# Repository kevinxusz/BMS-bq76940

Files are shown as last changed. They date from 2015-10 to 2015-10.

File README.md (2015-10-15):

battery managment system based on the BQ76940 from Texus Instruments

This project supports akkupacks from 9 to 15 serial Li-Ion based cells (max. Voltage ~63 Volt). It can balance each cell and turns the charge and discharge MOSFETs to control the system over i2c.

Measuring:

- up to 15 cell voltages
- akkupack voltage
- tempreature (internal + external)
- akkupack current

Protection:

- overcurrent in discharge
- overcurrent in discharge
- overvoltage
- undervoltage

My System

For the dokumentation see /Dokumentation/DA_MB_15.pdf where you can find my hole work (german). The important BMS part is shown in capter 5.

The realized system has the following specifications:

- µC: ATmega168PA
- programming was done in C with Linux in nano and the AVR-Tools (avr-gcc, avr-objcopy, make)
- to programm the µC i use avrdude over USB
- the current system is based on 15 cells and max. 60 Volts
- balancing and loading the akkupack
- balancingcurrent up to ~105 mA
- 3x temp. sensors
- switches current up to ~70 Ampere

All testing and programming was done with the developed EvalBoard. For schematica and layouts see /kicad (http://kicad-pcb.org/).
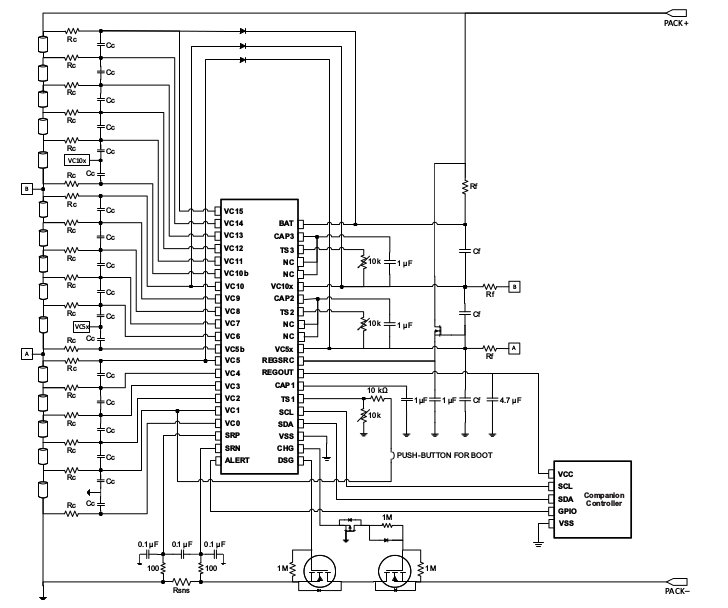
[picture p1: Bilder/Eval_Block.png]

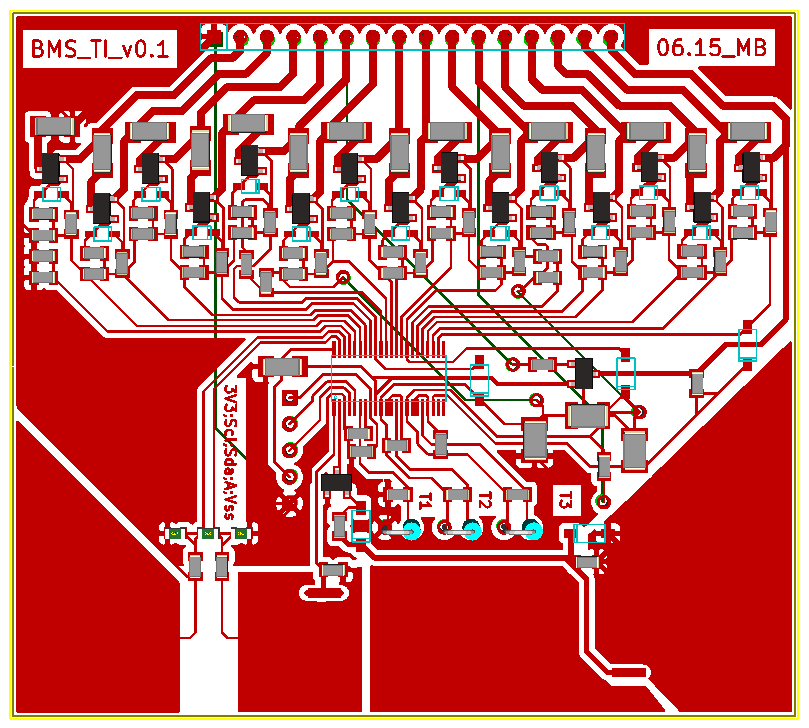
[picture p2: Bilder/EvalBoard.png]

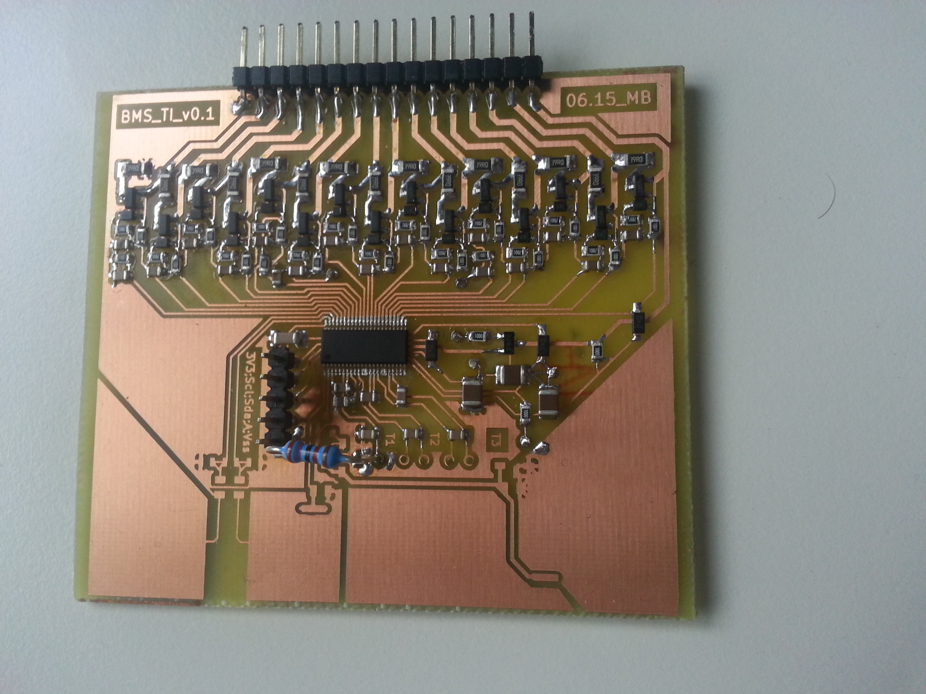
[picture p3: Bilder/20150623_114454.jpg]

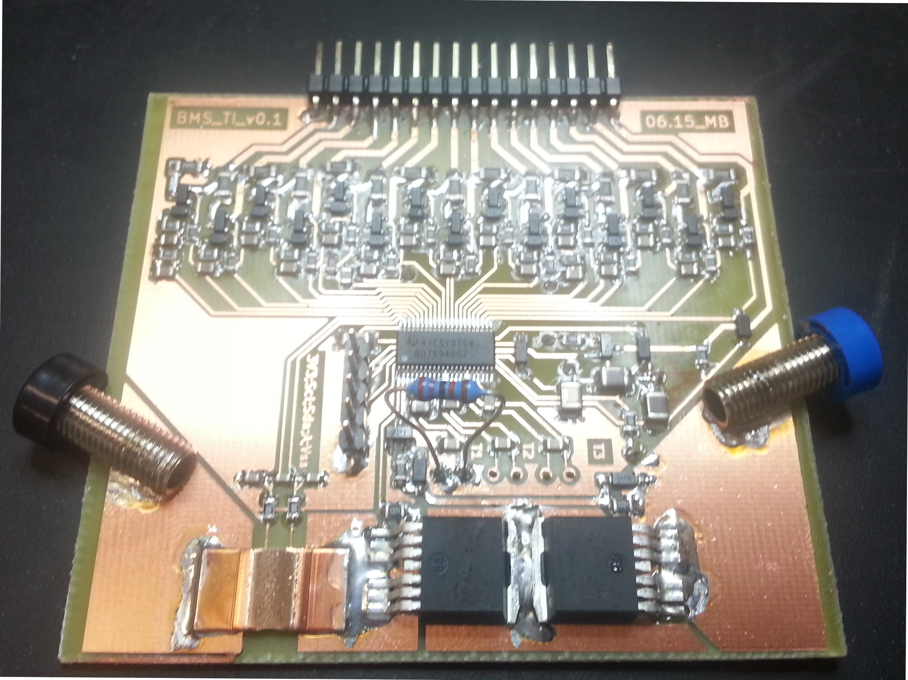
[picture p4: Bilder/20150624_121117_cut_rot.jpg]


For testing the given example run the Makefile (in /Quellcode/Anwendungsbeispiel):
(boot the BQ76940 with 3.3V on TS1) (bootet if 3.3V on REGOUT/3V3_init)

    make clean
    make all
    sudo make load

ToDO:

testing heating distribution under use
testing current measuring funktion

License Information

This code is public domain to support electromobility and is a collaboration between Nathan Seidle (https://github.com/nseidle/BMS) and me.

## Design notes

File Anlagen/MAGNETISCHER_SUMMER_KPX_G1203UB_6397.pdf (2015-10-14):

## Technical datasheet: KPX-G1203UB-K6397

Specifications:

Operating Temperature | -20ºC to +70ºC
Storage Temperature | -30ºC to +80ºC
Rated Voltage | 3 VDC
Operating Voltage | 2VDC to 5VDC
Max. Rated Current | 30mA at 3 VDC
Resonant Frequency | 2.3kHz±0.5kHz
Min SPL | 85dB/ 3VDC/ 10cm
Weight | 2g
Case Material/Color | PBT/Black
Tone Nature | Continuous

Dimensions:

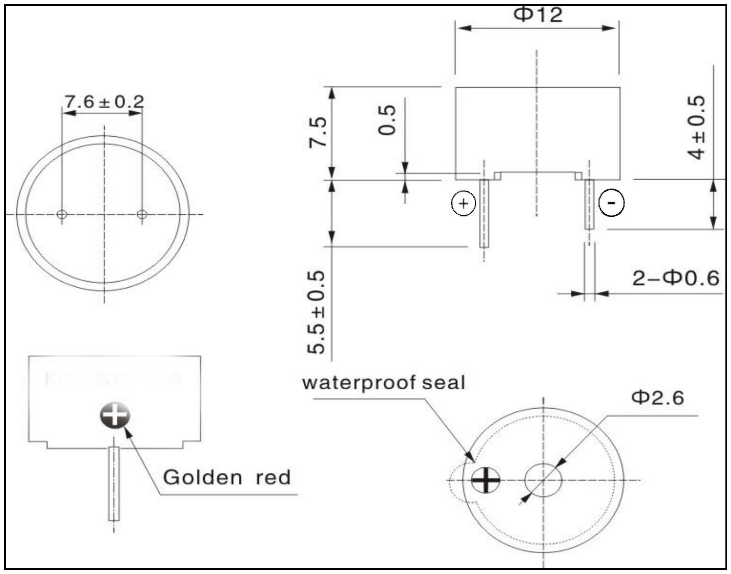
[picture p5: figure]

Frequency Response:

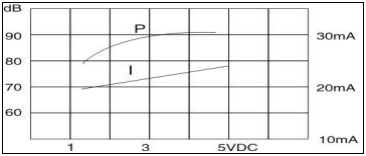
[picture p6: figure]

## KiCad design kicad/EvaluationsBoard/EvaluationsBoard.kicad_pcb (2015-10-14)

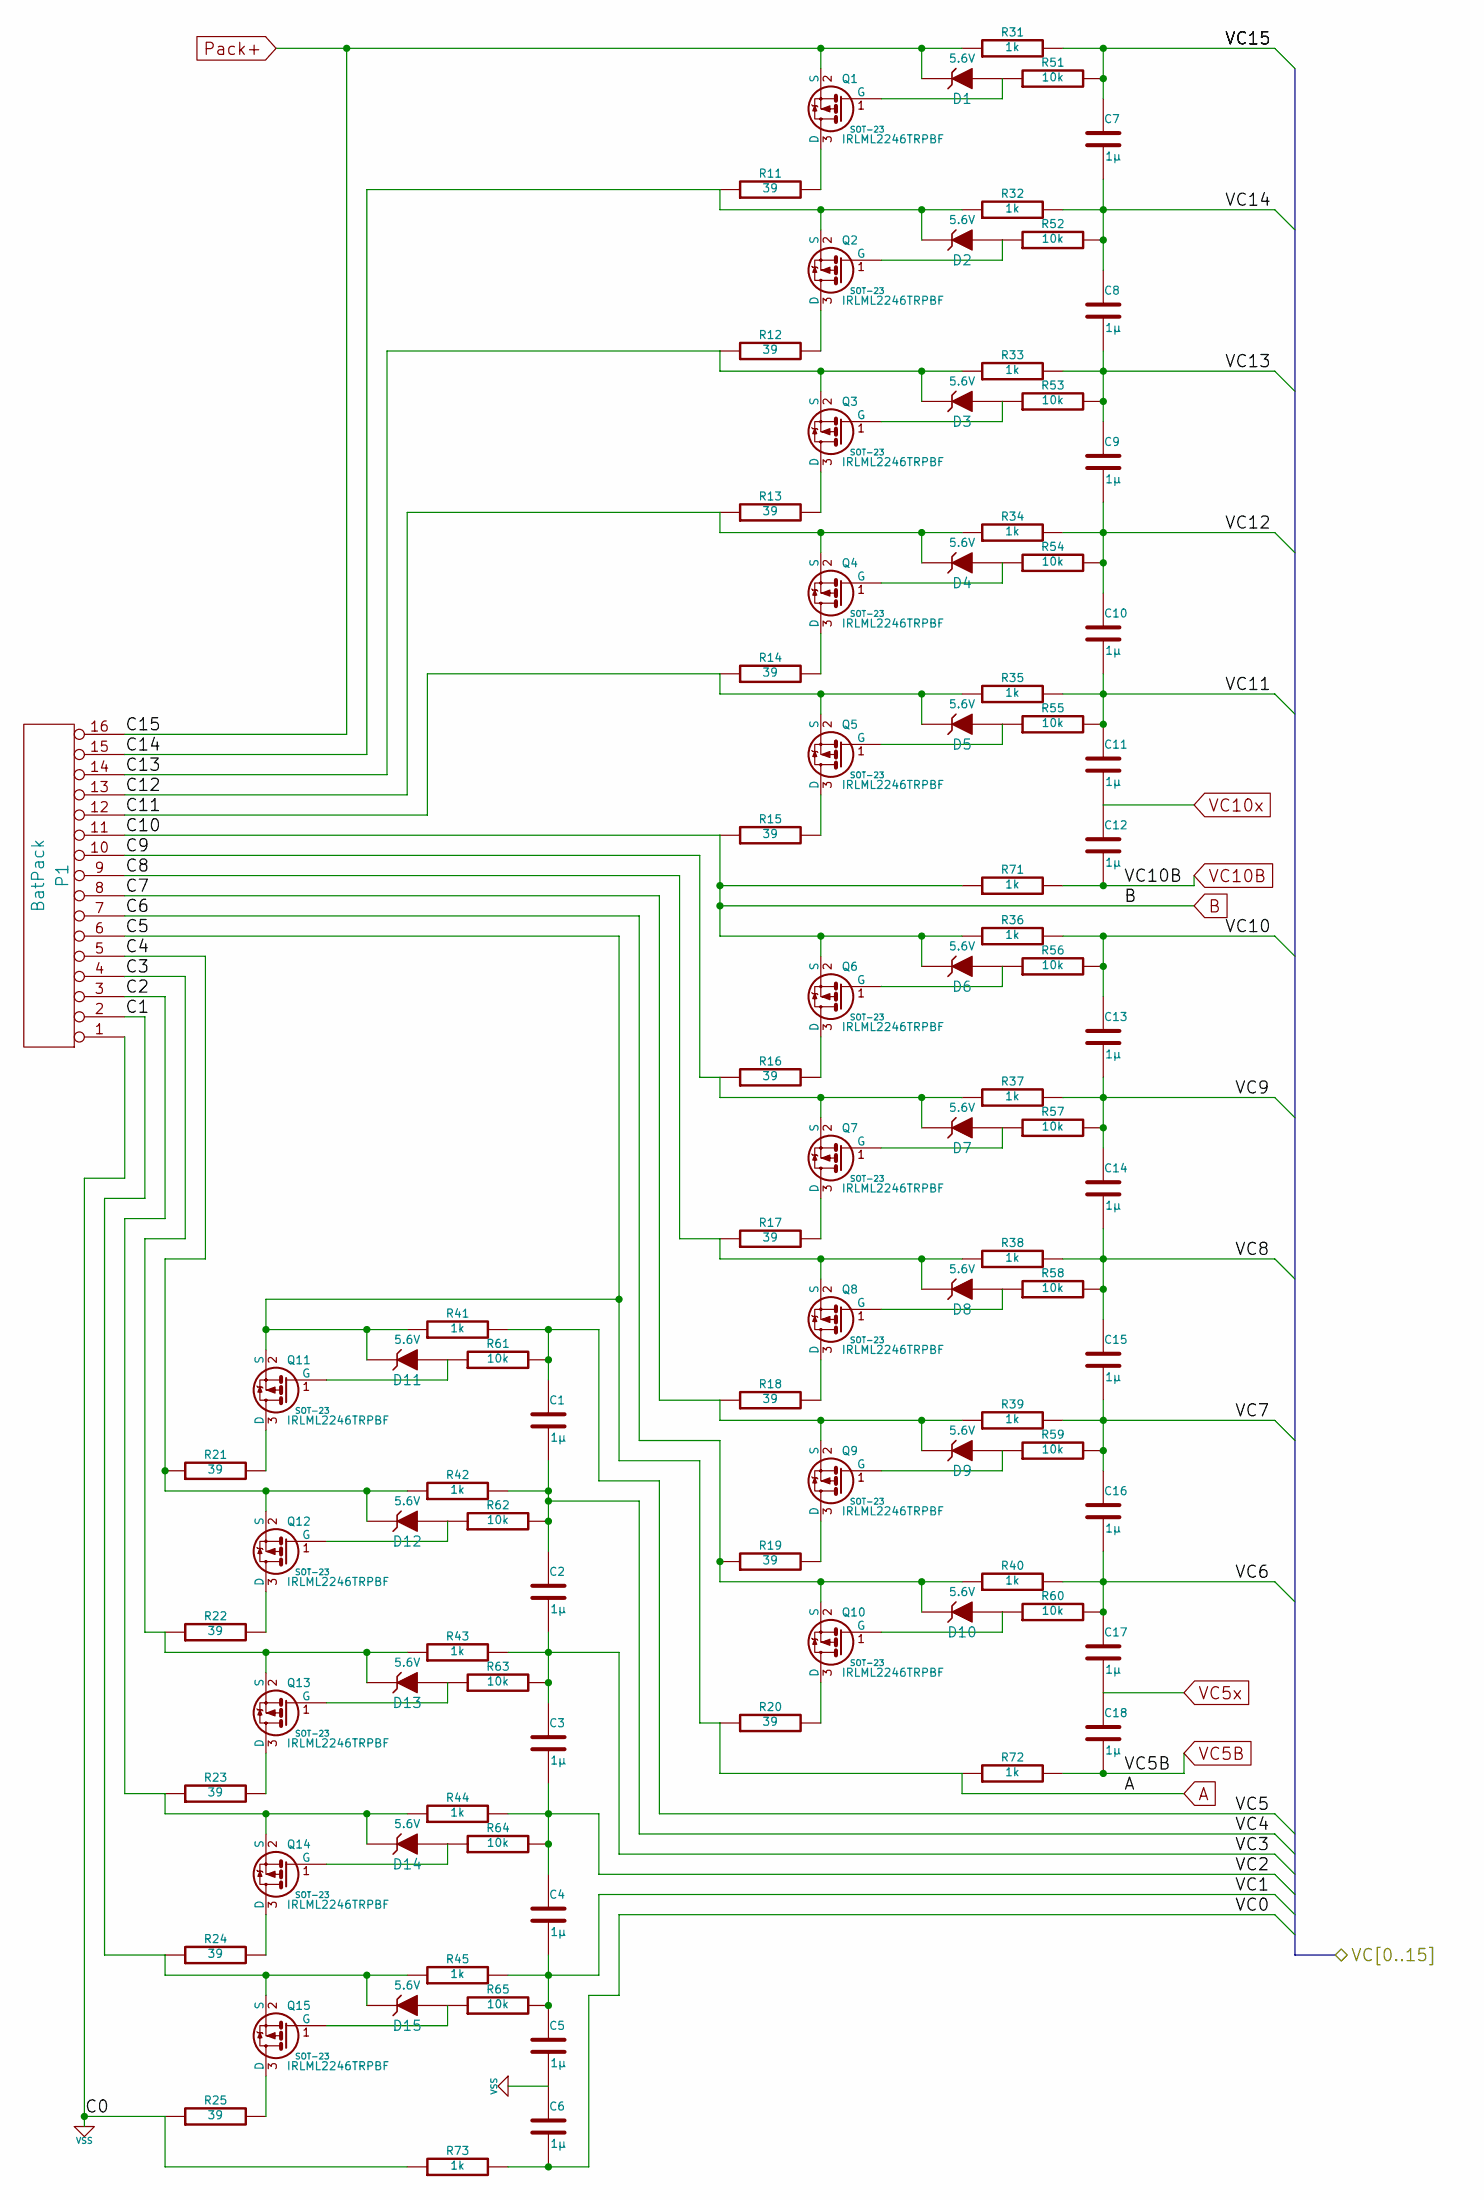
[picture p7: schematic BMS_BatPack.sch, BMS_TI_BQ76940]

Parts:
C1, C2, C3, C4, C5, C6, C7, C8, C9, C10, C11, C12, C13, C14, C15, C16, C17, C18: 1µ
D1, D2, D3, D4, D5, D6, D7, D8, D9, D10, D11, D12, D13, D14, D15: 5.6V
P1: BatPack
Q1, Q2, Q3, Q4, Q5, Q6, Q7, Q8, Q9, Q10, Q11, Q12, Q13, Q14, Q15: IRLML2246TRPBF; SOT-23
R11, R12, R13, R14, R15, R16, R17, R18, R19, R20, R21, R22, R23, R24, R25: 39
R31, R32, R33, R34, R35, R36, R37, R38, R39, R40, R41, R42, R43, R44, R45, R71, R72, R73: 1k
R51, R52, R53, R54, R55, R56, R57, R58, R59, R60, R61, R62, R63, R64, R65: 10k

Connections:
/BatPack/C1: D15.2 (K), P1.2, Q15.2 (S), R24.1, R45.1
/BatPack/C2: D14.2 (K), P1.3, Q14.2 (S), R23.1, R44.1
/BatPack/C3: D13.2 (K), P1.4, Q13.2 (S), R22.1, R43.1
/BatPack/C4: D12.2 (K), P1.5, Q12.2 (S), R21.1, R42.1
/BatPack/C6: D10.2 (K), P1.7, Q10.2 (S), R19.1, R40.1
/BatPack/C7: D9.2 (K), P1.8, Q9.2 (S), R18.1, R39.1
/BatPack/C8: D8.2 (K), P1.9, Q8.2 (S), R17.1, R38.1
/BatPack/C9: D7.2 (K), P1.10, Q7.2 (S), R16.1, R37.1
/BatPack/C11: D5.2 (K), P1.12, Q5.2 (S), R14.1, R35.1
/BatPack/C12: D4.2 (K), P1.13, Q4.2 (S), R13.1, R34.1
/BatPack/C13: D3.2 (K), P1.14, Q3.2 (S), R12.1, R33.1
/BatPack/C14: D2.2 (K), P1.15, Q2.2 (S), R11.1, R32.1
/BatPack/VC0: C6.2, R73.2; also elsewhere on the board
/BatPack/VC1: C4.2, C5.1, R45.2, R65.2; also elsewhere on the board
/BatPack/VC2: C3.2, C4.1, R44.2, R64.2; also elsewhere on the board
/BatPack/VC3: C2.2, C3.1, R43.2, R63.2; also elsewhere on the board
/BatPack/VC4: C1.2, C2.1, R42.2, R62.2; also elsewhere on the board
/BatPack/VC5: C1.1, R41.2, R61.2; also elsewhere on the board
/BatPack/VC6: C16.2, C17.1, R40.2, R60.2; also elsewhere on the board
/BatPack/VC7: C15.2, C16.1, R39.2, R59.2; also elsewhere on the board
/BatPack/VC8: C14.2, C15.1, R38.2, R58.2; also elsewhere on the board
/BatPack/VC9: C13.2, C14.1, R37.2, R57.2; also elsewhere on the board
/BatPack/VC10: C13.1, R36.2, R56.2; also elsewhere on the board
/BatPack/VC11: C10.2, C11.1, R35.2, R55.2; also elsewhere on the board
/BatPack/VC12: C9.2, C10.1, R34.2, R54.2; also elsewhere on the board
/BatPack/VC13: C8.2, C9.1, R33.2, R53.2; also elsewhere on the board
/BatPack/VC14: C7.2, C8.1, R32.2, R52.2; also elsewhere on the board
/BatPack/VC15: C7.1, R31.2, R51.2; also elsewhere on the board
A: D11.2 (K), P1.6, Q11.2 (S), R20.1, R41.1, R72.1; also elsewhere on the board
B: D6.2 (K), P1.11, Q6.2 (S), R15.1, R36.1, R71.1; also elsewhere on the board
unnamed: D5.1 (A), Q5.1 (G), R55.1
unnamed: D3.1 (A), Q3.1 (G), R53.1
unnamed: D4.1 (A), Q4.1 (G), R54.1
unnamed: D6.1 (A), Q6.1 (G), R56.1
unnamed: D2.1 (A), Q2.1 (G), R52.1
unnamed: D1.1 (A), Q1.1 (G), R51.1
unnamed: Q3.3 (D), R13.2
unnamed: Q4.3 (D), R14.2
unnamed: Q5.3 (D), R15.2
unnamed: Q6.3 (D), R16.2
unnamed: Q7.3 (D), R17.2
unnamed: Q8.3 (D), R18.2
unnamed: D9.1 (A), Q9.1 (G), R59.1
unnamed: Q9.3 (D), R19.2
unnamed: D10.1 (A), Q10.1 (G), R60.1
unnamed: Q1.3 (D), R11.2
unnamed: Q2.3 (D), R12.2
unnamed: Q14.3 (D), R24.2
unnamed: Q13.3 (D), R23.2
unnamed: Q12.3 (D), R22.2
unnamed: Q11.3 (D), R21.2
unnamed: Q10.3 (D), R20.2
unnamed: Q15.3 (D), R25.2
unnamed: D11.1 (A), Q11.1 (G), R61.1
unnamed: D12.1 (A), Q12.1 (G), R62.1
unnamed: D14.1 (A), Q14.1 (G), R64.1
unnamed: D7.1 (A), Q7.1 (G), R57.1
unnamed: D8.1 (A), Q8.1 (G), R58.1
unnamed: D13.1 (A), Q13.1 (G), R63.1
unnamed: D15.1 (A), Q15.1 (G), R65.1
PACK+: D1.2 (K), P1.16, Q1.2 (S), R31.1; also elsewhere on the board
VC5B: C18.2, R72.2; also elsewhere on the board
VC5x: C17.2, C18.1; also elsewhere on the board
VC10B: C12.2, R71.2; also elsewhere on the board
VC10x: C11.2, C12.1; also elsewhere on the board
VSS: C5.2, C6.1, P1.1, R25.1, R73.1; also elsewhere on the board

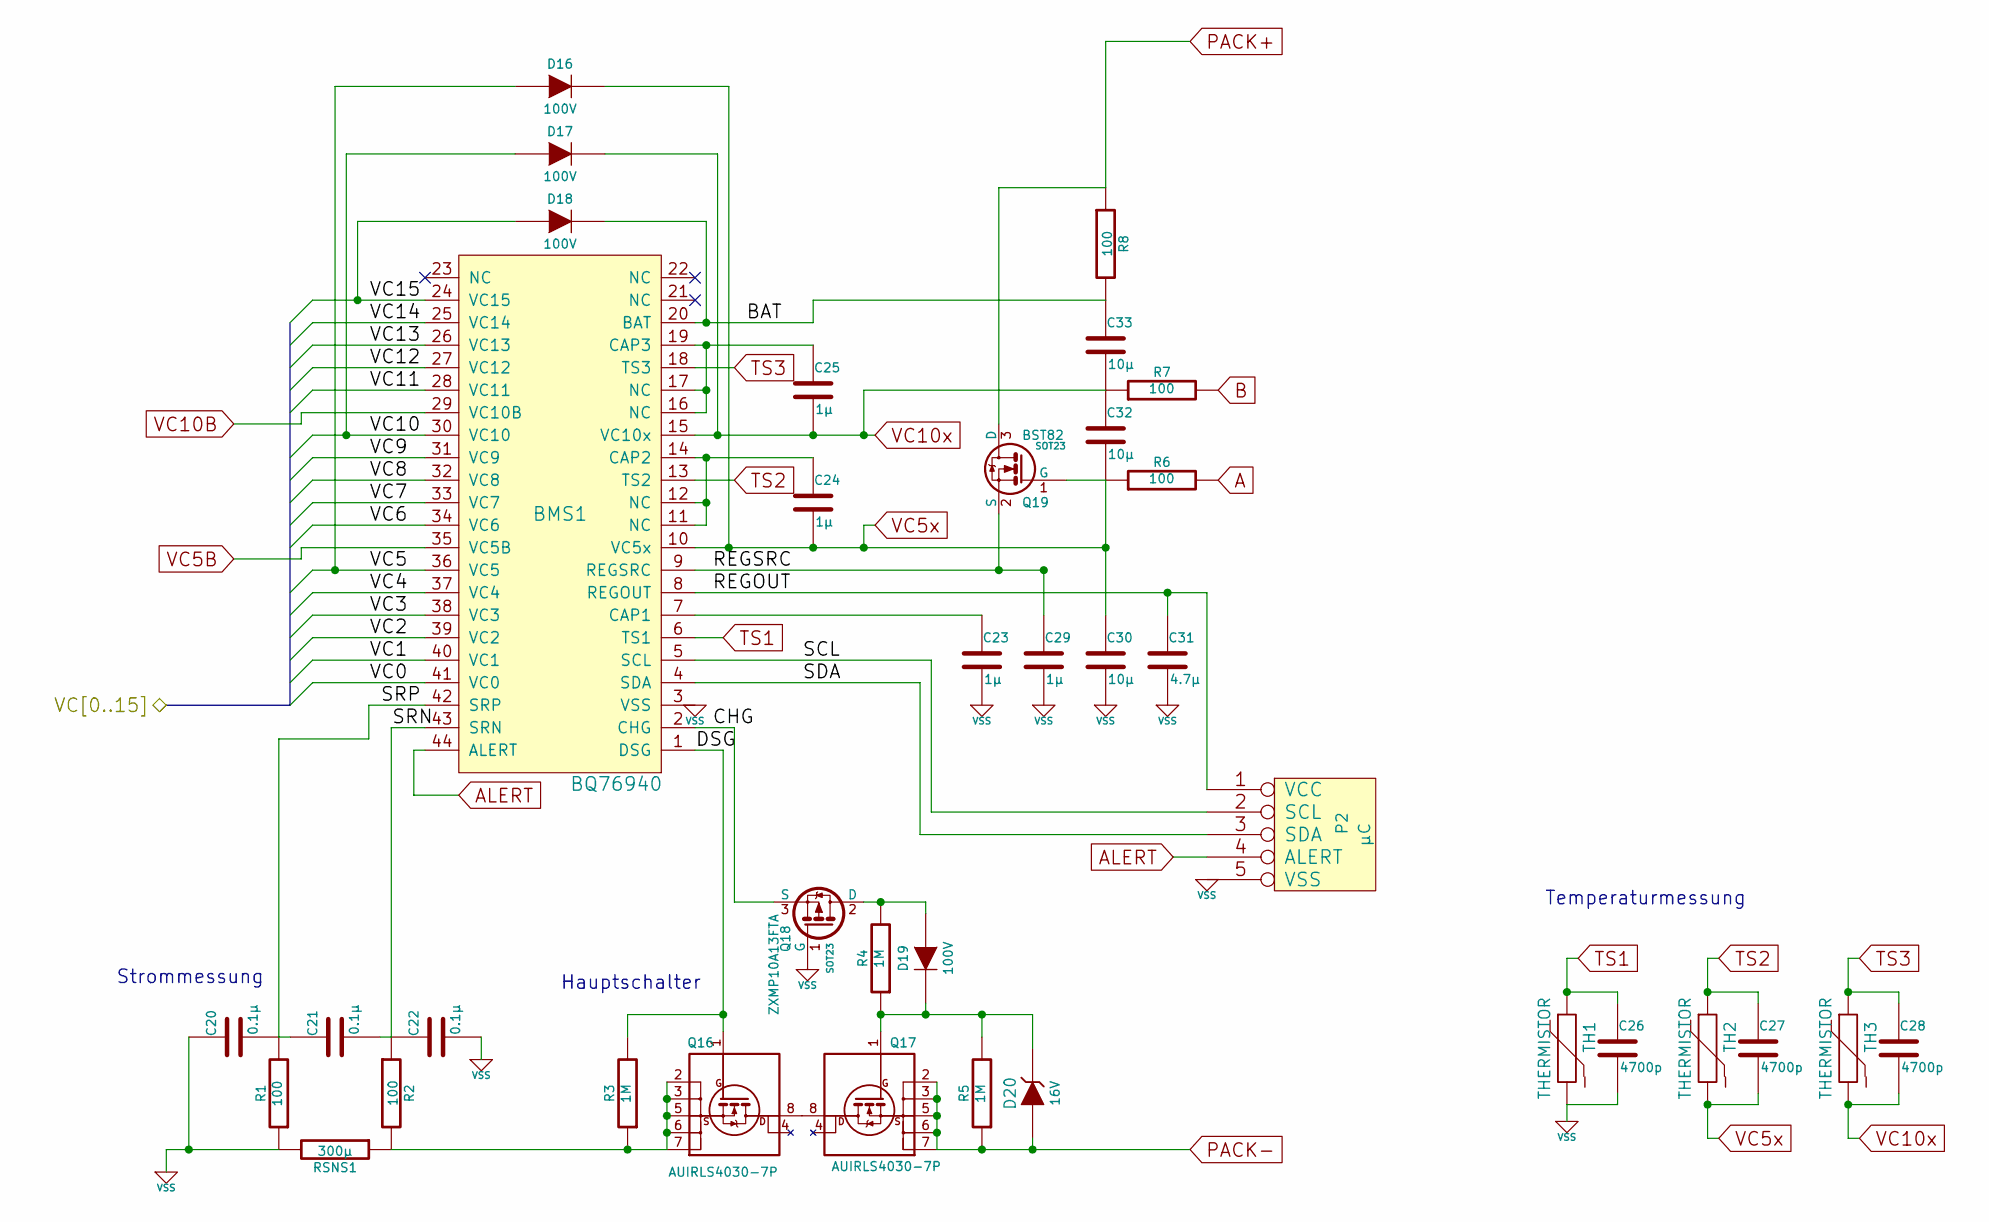
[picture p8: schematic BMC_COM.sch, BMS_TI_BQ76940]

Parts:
BMS1: BQ76940
C20, C21, C22: 0.1µ
C23, C24, C25, C29: 1µ
C26, C27, C28: 4700p
C30, C32, C33: 10µ
C31: 4.7µ
D16, D17, D18, D19: 100V
D20: 16V
P2: µC
Q16, Q17: AUIRLS4030-7P
Q18: ZXMP10A13FTA; SOT23
Q19: BST82; SOT23
R1, R2, R6, R7, R8: 100
R3, R4, R5: 1M
RSNS1: 300µ
TH1, TH2, TH3: THERMISTOR

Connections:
/BatPack/VC0: BMS1.41 (VC0); also elsewhere on the board
/BatPack/VC1: BMS1.40 (VC1); also elsewhere on the board
/BatPack/VC2: BMS1.39 (VC2); also elsewhere on the board
/BatPack/VC3: BMS1.38 (VC3); also elsewhere on the board
/BatPack/VC4: BMS1.37 (VC4); also elsewhere on the board
/BatPack/VC5: BMS1.36 (VC5), D16.1 (A); also elsewhere on the board
/BatPack/VC6: BMS1.34 (VC6); also elsewhere on the board
/BatPack/VC7: BMS1.33 (VC7); also elsewhere on the board
/BatPack/VC8: BMS1.32 (VC8); also elsewhere on the board
/BatPack/VC9: BMS1.31 (VC9); also elsewhere on the board
/BatPack/VC10: BMS1.30 (VC10), D17.1 (A); also elsewhere on the board
/BatPack/VC11: BMS1.28 (VC11); also elsewhere on the board
/BatPack/VC12: BMS1.27 (VC12); also elsewhere on the board
/BatPack/VC13: BMS1.26 (VC13); also elsewhere on the board
/BatPack/VC14: BMS1.25 (VC14); also elsewhere on the board
/BatPack/VC15: BMS1.24 (VC15), D18.1 (A); also elsewhere on the board
/COM/BAT: BMS1.20 (BAT), C33.1, D18.2 (K), R8.2
/COM/CHG: BMS1.2 (CHG), Q18.3 (S)
/COM/DSC: BMS1.1 (DSG), Q16.1 (G), R3.2
/COM/REGOUT: BMS1.8 (REGOUT), C31.1, P2.1 (VCC)
/COM/REGSRC: BMS1.9 (REGSRC), C29.1, Q19.2 (S)
/COM/SCL: BMS1.5 (SCL), P2.2 (SCL)
/COM/SDA: BMS1.4 (SDA), P2.3 (SDA)
/COM/SRN: BMS1.43 (SRN), C21.2, C22.1, R2.1
/COM/SRP: BMS1.42 (SRP), C20.2, C21.1, R1.2
A: R6.2; also elsewhere on the board
ALERT: BMS1.44 (ALERT), P2.4 (ALERT)
B: R7.2; also elsewhere on the board
unnamed: BMS1.7 (CAP1), C23.1
unnamed: BMS1.16 (NC), BMS1.17 (NC), BMS1.19 (CAP3), C25.1
unnamed: BMS1.11 (NC), BMS1.12 (NC), BMS1.14 (CAP2), C24.1
unnamed: D19.2 (K), D20.2 (K), Q17.1 (G), R4.1, R5.2
unnamed: Q16.8 (D), Q17.8 (D)
unnamed: D19.1 (A), Q18.2 (D), R4.2
unnamed: Q16.2, Q16.3, Q16.5, Q16.6, Q16.7, R2.2, R3.1, RSNS1.1
PACK+: Q19.3 (D), R8.1; also elsewhere on the board
PACK-: D20.1 (A), Q17.2, Q17.3, Q17.5, Q17.6, Q17.7, R5.1
TS1: BMS1.6 (TS1), C26.1, TH1.1
TS2: BMS1.13 (TS2), C27.1, TH2.1
TS3: BMS1.18 (TS3), C28.1, TH3.1
VC5B: BMS1.35 (VC5B); also elsewhere on the board
VC5x: BMS1.10 (VC5x), C24.2, C27.2, C30.1, C32.2, D16.2 (K), Q19.1 (G), R6.1, TH2.2; also elsewhere on the board
VC10B: BMS1.29 (VC10B); also elsewhere on the board
VC10x: BMS1.15 (VC10x), C25.2, C28.2, C32.1, C33.2, D17.2 (K), R7.1, TH3.2; also elsewhere on the board
VSS: BMS1.3 (VSS), C20.1, C22.2, C23.2, C26.2, C29.2, C30.2, C31.2, P2.5 (VSS), Q18.1 (G), R1.1, RSNS1.2, TH1.2; also elsewhere on the board

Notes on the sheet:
Strommessung
Temperaturmessung
Hauptschalter

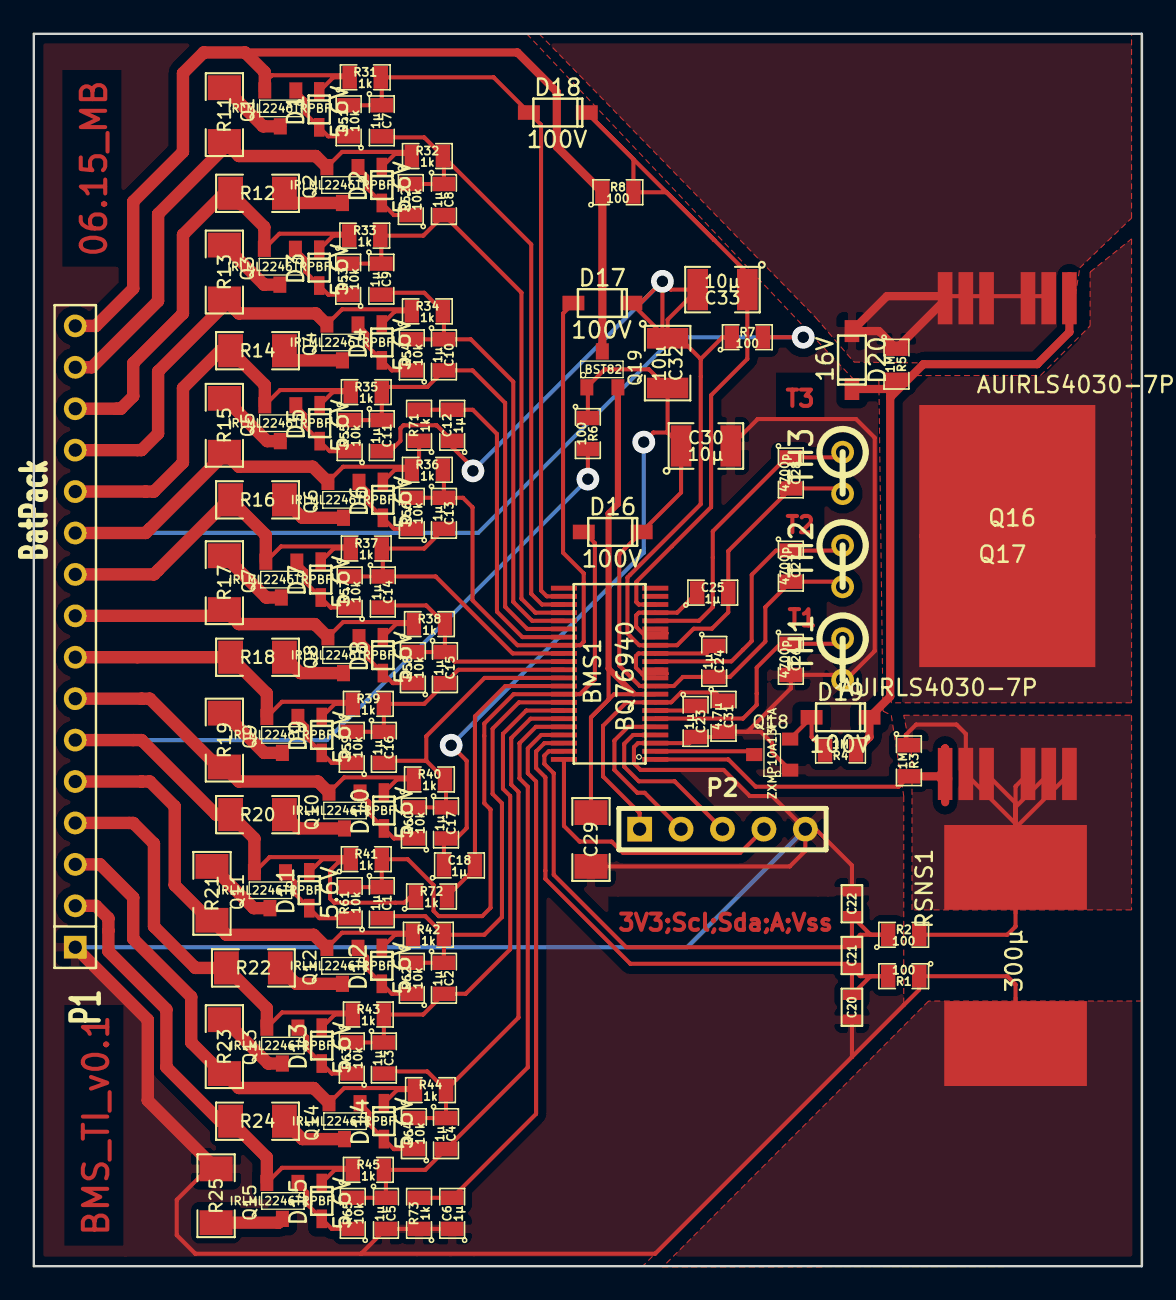
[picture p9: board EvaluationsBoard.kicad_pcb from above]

Board: 2 copper layers, 67.9 x 75.6 mm, 134 parts (0 on the bottom side), 87 nets.

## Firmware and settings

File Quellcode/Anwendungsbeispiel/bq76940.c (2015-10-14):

uint8_t bq76940_init(void)
{
	uint8_t error = 0;

// make sure the bq is booted up--->set TS1 to 3.3V and back to VSS
// maybe set temp-mode for internal or external temp here

	// enable ADC
	error |= registerWrite(SYS_CTRL1, ADC_EN);
	// check if ADC is active
	if(!(registerRead(SYS_CTRL1) & ADC_EN)) { return ERROR_ADC; }

	// write 0x19 to CC_CFG according to datasheet page 39
	error |= registerWrite(CC_CFG, 0x19);

	gain = gainRead();      				// get gain
	if( (gain<365) | (gain>396) ) { return ERROR_GAIN; };	// check gain

	offset = offsetRead();  // get offset
	// if( (offset<0x00) | (offset>0xFF) ) { return 1; };	// dont check offset

	error |= UVtripWrite();	// write OV_TRIP
	error |= OVtripWrite();	// write UV_TRIP

// für 30 A Hauptschalter // Versuchszwecke
//	error |= registerWrite(PROTECT1, 0x00);	// write PROTECT1
//	error |= registerWrite(PROTECT2, 0x00);	// write PROTECT2
//	error |= registerWrite(PROTECT3, 0x50);	// write PROTECT3

// für 190 A Hauptschalter
	error |= registerWrite(PROTECT1, 0x0B);	// write PROTECT1
	error |= registerWrite(PROTECT2, 0x9C);	// write PROTECT2
	error |= registerWrite(PROTECT3, 0x50);	// write PROTECT3

	// clear SYS-STAT for init
	if( registerRead(SYS_STAT) ) { checkSTAT(); }

	// doublecheck if bq is ready
	if(registerRead(SYS_STAT) & DEVICE_XREADY)
	{
		// DEVICE_XREADY is set
		// write 1 in DEVICE_XREADY to clear it
		error |= registerWrite(SYS_STAT, DEVICE_XREADY);
		// check again
		if(registerRead(SYS_STAT) & DEVICE_XREADY) { return ERROR_XREADY; }
	}

	// enable countinous reading of the Coulomb Counter
//	error |= registerWrite(SYS_CTRL2, CC_EN);	// sets ALERT at 250ms interval to high


	return error; // 0 if successful
}

uint8_t enterShipMode(void)
{
	uint8_t error = 0;
	uint8_t ctrl1 = registerRead(SYS_CTRL1);

	// clear SHUT_A and SHUT_B
	ctrl1 &= 0xFC;
	error |= registerWrite(SYS_CTRL1, ctrl1);

	// SHUT_A=0, SHUT_B=1
	ctrl1 |= 0x01;
	error |= registerWrite(SYS_CTRL1, ctrl1);

	// SHUT_A=1, SHUT_B=0
	ctrl1 |= 0x01;
	error |= registerWrite(SYS_CTRL1, ctrl1);

	return error; // 0 if successful
}

uint16_t gainRead(void)
{
	uint8_t reg1 = registerRead(ADCGAIN1);
	uint8_t reg2 = registerRead(ADCGAIN2);

	reg1 &= 0b00001100;

	return (365 + ((reg1 << 1)|(reg2 >> 5)));
}

int8_t offsetRead(void)
{
	return registerRead(ADCOFFSET);
}

uint16_t PackVoltageRead(void)
{
	uint32_t packADC = registerDoubleRead(BAT_HI);

	return (((4*gain*(packADC))/1000)+(NUMBER_OF_CELLS*offset));	// Cellstack Voltage in mV
}

uint16_t CellVoltageRead(uint8_t cellregister) // need VCX_HI !!!!!
{
	uint32_t cellADC = 0;

	cellADC = registerDoubleRead(cellregister);

	return (((cellADC*gain)/1000)+offset);				// returns voltage in mV
}

uint8_t CellArrayVoltageRead(uint16_t cellV[])
{
	uint8_t i=0;
	uint8_t error=0;

	error=registerArrayRead(VC1_HI, cellV, NUMBER_OF_CELLS);

	for(;i<NUMBER_OF_CELLS;i++)
	{
		cellV[i] = ((((uint32_t)cellV[i]*gain)/1000)+offset);
	}

	return error;
}

//calculates a Voltage back in ADC and strips the middle 8-Bits
uint8_t tripCalculator(uint32_t thershold)
{
	thershold -= offset;
	thershold *= 1000;
	thershold /= gain;
	thershold++;		//Nachkommastellenkorrektur
	thershold >>= 4;

	return ((uint8_t)thershold);
}

uint8_t OVtripWrite(void)
{
	return ( registerWrite(OV_TRIP, tripCalculator(OV_THERSHOLD)) ); // 0 => successful
}

uint8_t UVtripWrite(void)
{
	return ( registerWrite(UV_TRIP, tripCalculator(UV_THERSHOLD)) ); // 0 => successful
}

// measures one of the 4 Tempsensors(1xint., 3xext.)
// number: 0 for internal, 1 for TS1, 2 for TS2 and 3 for TS3
// TEMP_SEL: internal=0, external=1
// notice that a 2-s delay is needed by switching internal and external
int16_t TempRead(uint8_t number)
{
	uint8_t ctrl1 = (registerRead(SYS_CTRL1));
	int32_t temp = 0;

	// calc internal temp
	if(number == 0)
	{
		// check if TEMP_SEL=1 for externel-mode, then clear TEMP_SET and wait
		if(ctrl1 & TEMP_SEL) { registerWrite(SYS_CTRL1, (ctrl1 & ~(TEMP_SEL)) ); _delay_ms(2000); }

		// read tempADC
		temp = registerDoubleRead(TS2_HI);

		// real: -60°C..150°C in (return:) -6000c°C..15000c°C [DS_S.24]
		return (25000-((((temp*382)/1000)-1200)*238))/10;
	}

	// calc externel temp
	// check if TEMP_SEL=0 for internel-mode, then set TEMP_SET and wait
	if( !(ctrl1 & TEMP_SEL) ) { registerWrite(SYS_CTRL1, (ctrl1  | (TEMP_SEL)) ); _delay_ms(2000); } // wait for update

	// read tempADC
	temp = registerDoubleRead(TS1_HI+2*(number-1));

	// calc R_TS [DS_S.23]
	temp = (temp*382)/1000;		// mV
	temp = (10000*temp)/(3300-temp);// V/A
	temp = RtoT((uint16_t)temp);

	// return TSX in °C in 5°C-Schritten
	return temp;
}

int16_t CurrentRead(void)
{
	int16_t cur = registerDoubleRead(CC_HI);

	cur = ((int32_t)cur*(844/R_SHUNT))/100;

	//measurement area: -327.68A..327.67A // Gültigkeitsbereich(return): -32768cA..32767cA // Auflösung: 30mA
	return cur;
	// 8.44µV=844cµV
	// I=U/R=cµV/(µV/A)=CµVA/µV=cA
}

// checks BalancingBits(5-Bitregister) in 3x 5er-Gruppen
// erlaubte Registerkombinationen(dez.): 1 2 4 5 8 9 10 12 16 17 18 20 21 24 25 (Cell1:2^0; Cell2:2^1; Cell3:2^2....)
// return:
// 1: Fehler Bitkombination im Register unsicher
// 0: Bitkombination ist sicher
uint8_t BalancRegCheck(uint8_t bal_reg)
{
	if( ((bal_reg <= 5) | (!(bal_reg <= 7) & (bal_reg <= 10)) | ((bal_reg >= 16) & !(bal_reg > 25)) | (bal_reg == 12) ))
	{
		if((bal_reg == 3) | (bal_reg == 19) | (bal_reg == 23) | (bal_reg == 22)) { return 1; }
		else { return 0; }
	}
	return 1;
}

//splits unsafe Reg-combos in 2 x 8-Bit Register
//return: 5(-Bit=Reg1) + 5(LSB=Reg2) = 16-Bit = 0000001111122222
uint16_t BalancRegSplit(uint16_t bal_reg)
{
        return ( ((bal_reg & (1 << 4) ) << 5) | ((bal_reg & (1 << 2) ) << 5) | ((bal_reg & (1 << 0) ) << 5) ) | (bal_reg & (1 << 3)) | (bal_reg & (1 << 1) );
}

uint16_t Balancing(uint16_t cellV[NUMBER_OF_CELLS])
{
	uint8_t f=0, eps=ZUELS, finish=0, error=1;
	uint8_t bal_reg1, bal_reg2, bal_reg3, bal_reg10=0, bal_reg20=0, bal_reg30=0;
	uint16_t celllow=0, cellbal=0, bal_reg = 0;
	int16_t temp=0;

	// get all Cellvoltages
	CellArrayVoltageRead(cellV);

	celllow = cellV[0];
	// find cell with the lowest voltage
	for(f=1;f<NUMBER_OF_CELLS;f++) { if(cellV[f] < celllow) { celllow = cellV[f]; } }

	// check if one or more cells are at ZLSS+eps
	for(f=0;f<NUMBER_OF_CELLS;f++) { finish += (cellV[f] >= ZLSS+eps); }
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

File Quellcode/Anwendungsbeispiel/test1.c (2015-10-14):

#define F_CPU 8000000UL
#include "globales.h"
#include "bq76940.h"
#include "uart.h"
#include "interrupt.h"
#include "i2c_bq76490.h"
#include "bq76940.c"


int main(void)
{

	int16_t i=0;
	uint16_t cellV[15] = {0};
	uint16_t data  = 0;
	uint16_t packV = 0;

	cli();	// Interrupts global deaktiviert

	DDRC  = 0xFF;			// Port C als Ausgangsport
	DDRD  = 0b11110010;		// set PD3(INT1(ALERT)) to input
	PORTD &= ~(1 << PD3);		// set input(PD3) to low (high if fault detected)

uart_init();
	i2c_init();
	if(bq76940_init()) { uart_send("BQ_init fails"); return 1; }
	interrupt_init();

//	sei();	// Interrupts global aktiviert



	registerWrite(CELLBAL1, 0);
	registerWrite(CELLBAL2, 0);
	registerWrite(CELLBAL3, 0);


	data = TempRead(0);
	sprintf(hex_s, "Ti: %i \n", data);
	uart_send(hex_s);

	data = TempRead(1);
	sprintf(hex_s, "Te: %u \n", data);
	uart_send(hex_s);

	data = TempRead(2);
	sprintf(hex_s, "Te: %u \n", data);
	uart_send(hex_s);

	data = TempRead(3);
	sprintf(hex_s, "Te: %u \n", data);
	uart_send(hex_s);

	data = TempRead(0);
	sprintf(hex_s, "Ti: %i \n", data);
	uart_send(hex_s);

	return 0;


while(1)
{
//	Balancing(cellV);
//	_delay_ms(2000); // nicht bei UART-Ausgabe

	CellArrayVoltageRead(cellV);
//	registerWrite(CELLBAL1, 0);
//	registerWrite(CELLBAL2, 0);
//	registerWrite(CELLBAL3, 0);

	data = registerRead(SYS_CTRL2);
	sprintf(hex_s, "C: %x; ", data);
	uart_send(hex_s);

	for(i=0;i<15; i++)
	{
		sprintf(hex_s, "%u; ", cellV[i]);
		uart_send(hex_s);
	}

	packV = PackVoltageRead();
	sprintf(hex_s, "%u \n", packV);
	uart_send(hex_s);

	_delay_ms(2000);
}

/*
/////////////// STROMERFASSUNG ///////////////////
//	registerWrite(SYS_STAT, OVRD_ALERT);
	registerWrite(SYS_STAT, CC_READY);
//	registerWrite(SYS_CTRL2, (registerRead(SYS_CTRL2) & ~(CC_EN)));	// clear
	registerWrite(SYS_CTRL2, (CC_ONESHOT));
	_delay_ms(1000);

	// check if INT1 is high; check whats wrong; clear bit
	if(EIFR & (1 << INTF1))
	{
//		checkSTAT();
		//current=CurrentRead();
		//clear INTF1 // write 1 into it
		EIFR |= (1 << INTF1);
	}

	current=CurrentRead();
	sprintf(hex_s, "I: %3i\n", current);
	uart_send(hex_s);
}*/

//	_delay_us(1000);
//	registerWrite(SYS_STAT, CC_READY);
////////////////////////////////////////////////

//	registerWrite(SYS_STAT, OVRD_ALERT);
//	registerWrite(SYS_STAT, CC_READY);

	data = registerRead(SYS_STAT);
	sprintf(hex_s, "STAT: %02x\n", data);
	uart_send(hex_s);
	data = registerRead(SYS_CTRL1);
	sprintf(hex_s, "CTRL1: %02x\n", data);
	uart_send(hex_s);
	data = registerRead(SYS_CTRL2);
	sprintf(hex_s, "CTRL2: %02x\n", data);
	uart_send(hex_s);

	return 0;
}
////////////////////////////// MAIN-ENDE /////////////////////////////////////

/*
	registerWrite(SYS_CTRL2, (registerRead(SYS_CTRL2) | (CHG_ON)));		// set
	data = registerRead(SYS_CTRL2);
	sprintf(hex_s, "CTRL2: %x\n", data);
	uart_send(hex_s);

	_delay_ms(10000);
	registerWrite(SYS_CTRL2, (registerRead(SYS_CTRL2) & ~(CHG_ON)));	// clear
	registerWrite(SYS_CTRL2, (registerRead(SYS_CTRL2) & ~(DSG_ON)));	// clear
	data = registerRead(SYS_CTRL2);
	sprintf(hex_s, "CTRL2: %x\n", data);
	uart_send(hex_s);
*/

/*
	registerWrite(SYS_STAT, CC_READY);
	registerWrite(SYS_STAT, DEVICE_XREADY);
	registerWrite(SYS_STAT, OVRD_ALERT);
	registerWrite(SYS_STAT, UV);
	registerWrite(SYS_STAT, OV);
	registerWrite(SYS_STAT, SCD);
	registerWrite(SYS_STAT, OCD);
*/

/*
	// check if INT1 is high; check whats wrong; clear bit
	if(EIFR & (1 << INTF1))
	{
		uart_send("INTF1 in set");
		checkSTAT();
		//clear INTF1 // write 1 into it
		EIFR |= (1 << INTF1);
	}
*/

/*	data = TempRead(0);
	sprintf(hex_s, "T: %i\n ", data);
	uart_send(hex_s);
*/

/*
/////////////// Entladen auf 58.5 VOLT/////////////
while(1) {
packV = PackVoltageRead();
	do
	{
		CellArrayVoltageRead(cellV);
		for(i=0;i<15; i++)
		{
			sprintf(hex_s, "%u; ", cellV[i]);
			uart_send(hex_s);
		}
		packV = PackVoltageRead();
		sprintf(hex_s, "%u\n", packV);
		uart_send(hex_s);

		//Entladen ein
		registerWrite(SYS_CTRL2, DSG_ON);

	}while(packV >= 58500); // 58.5 VOLT

	//Entladen ein
	registerWrite(SYS_CTRL2, 0);
}
////////////////////ENTLADEN//////////////////////
*/


/*
while(1) // Balancing
{
	data = Balancing(cellV);
//	_delay_ms(1000);
	for(i=0;i<15; i++)
	{
		sprintf(hex_s, "%u; ", cellV[i]);
		uart_send(hex_s);
	}
	packV = PackVoltageRead();
	sprintf(hex_s, "%u\n", packV);
	uart_send(hex_s);
}
*/


/*	registerWrite(SYS_STAT, 0x00);

	data = registerRead(SYS_STAT);
	sprintf(hex_s, "REG: %x\n", data);
	uart_send(hex_s);

	sprintf(hex_s, "offset: %i\n", offset);
	uart_send(hex_s);
	sprintf(hex_s, "gain: %i\n", gain);
	uart_send(hex_s);

*/


/*	data = registerRead(CELLBAL1);
	sprintf(hex_s, "data1: %x\n", data);
	uart_send(hex_s);
	data = registerRead(CELLBAL2);
	sprintf(hex_s, "data2: %x\n", data);
	uart_send(hex_s);
	data = registerRead(CELLBAL3);
	sprintf(hex_s, "data3: %x\n", data);
	uart_send(hex_s);

	data = CellVoltageRead(VC15_HI);
	sprintf(hex_s, "cell: %u\n", data);
	uart_send(hex_s);
*/
